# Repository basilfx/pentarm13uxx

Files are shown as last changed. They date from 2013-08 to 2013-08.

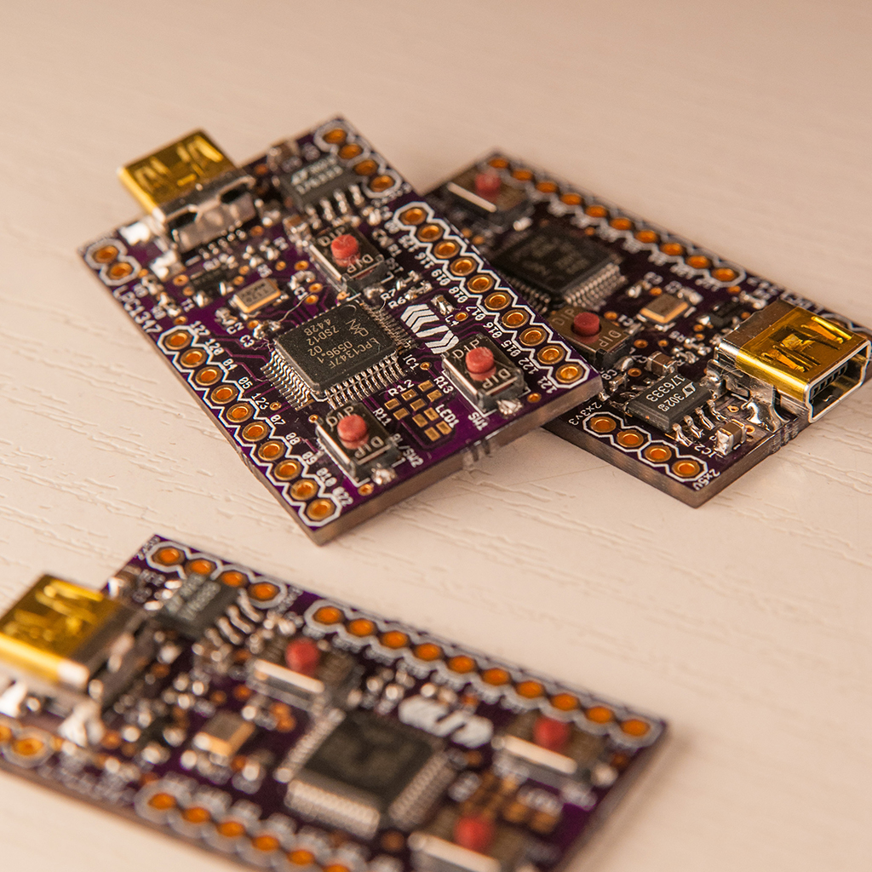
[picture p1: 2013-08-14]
doc/pcb.jpg

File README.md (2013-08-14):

endorse (http://coderwall.com/sebseb7)

pentarm13uxx
============

A small template project (blinking led) for the new lpc1347 (successor of the popular lpc1343).

Including Makefile, linker-script and cmsis and microcontroler header files.

Also includes eagle files for a small breaboardable eval-board.

- - -

####lpc1347 features

* 12k sram (was 8k)
* 64k flash (was 32k)
* 4k EEPROM (new)
* 72Mhz
* USART,I2C,2xSPI
* 12Bit ADC (new)
* USB_MSC, USB_HID, USB_CDC and USB_DFU in rom (new)
* usb-bootloader in rom

- - -

price of the eval board: ~$15

- - -

####BOM:

* C1,C2 : 22pF 0402
* C3,C4 : 100nF 0402
* C6,C8 : 10nF 0402
* C5,C7 : 1µF 0805
* R2,R3,R6,R7 : 150R 0402
* R4,R5 : 33R 0402
* R1,R8,R9 : 15k 0402
* R10 : 1k5 0402
* T1 : Si3102DS SOT23 (or other pfet)
* Q1 : 12Mhz MT (farnell: 1842056)
* IC1 : lpc1347 QFP48 (farnell: 2103477)
* IC2 : LT1763CS8-3.3 SOIC8 (farnell: 1273617)
* X1 : Mini USB Connector SMD (farnell: 1125348)
* X2,X3 : Pin-Header 10 Pin
* X4 : Pin Header 2 Pin
* X5 : Pin Header 4 Pin
* LED1 : RGB LED PLCC4 common annode
* SW1,SW2,RST : MCTAEF-25N (farnell:1605484)

- - -

data sheet  : http://www.nxp.com/documents/data_sheet/LPC1315_16_17_45_46_47.pdf

user manual : http://www.nxp.com/documents/user_manual/UM10524.pdf

toolchain   : https://launchpad.net/gcc-arm-embedded

- - -   
brd
Board top render

pcb Completed boards, photo by [Dirk Soeteman](http://www.dirksoeteman.nl/)

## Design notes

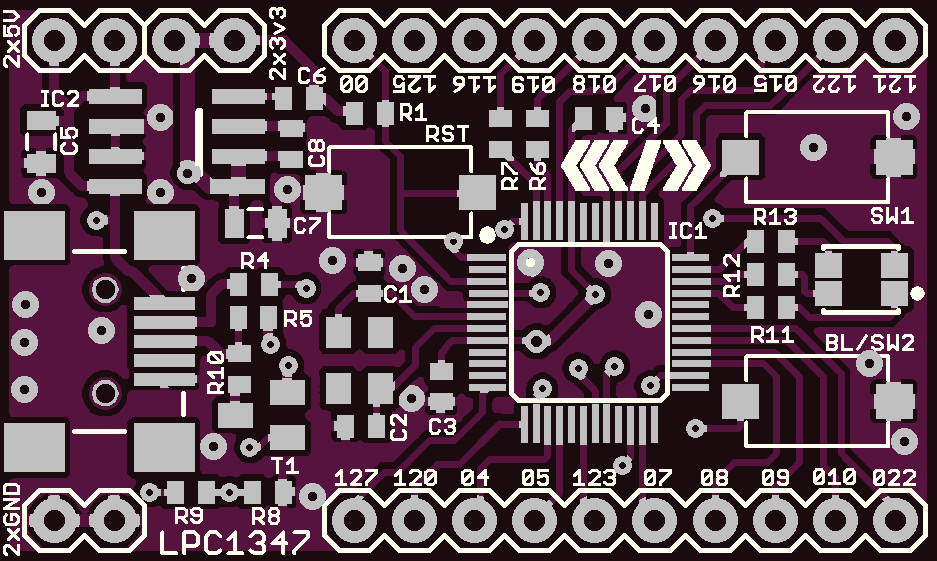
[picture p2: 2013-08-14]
doc/brd.png

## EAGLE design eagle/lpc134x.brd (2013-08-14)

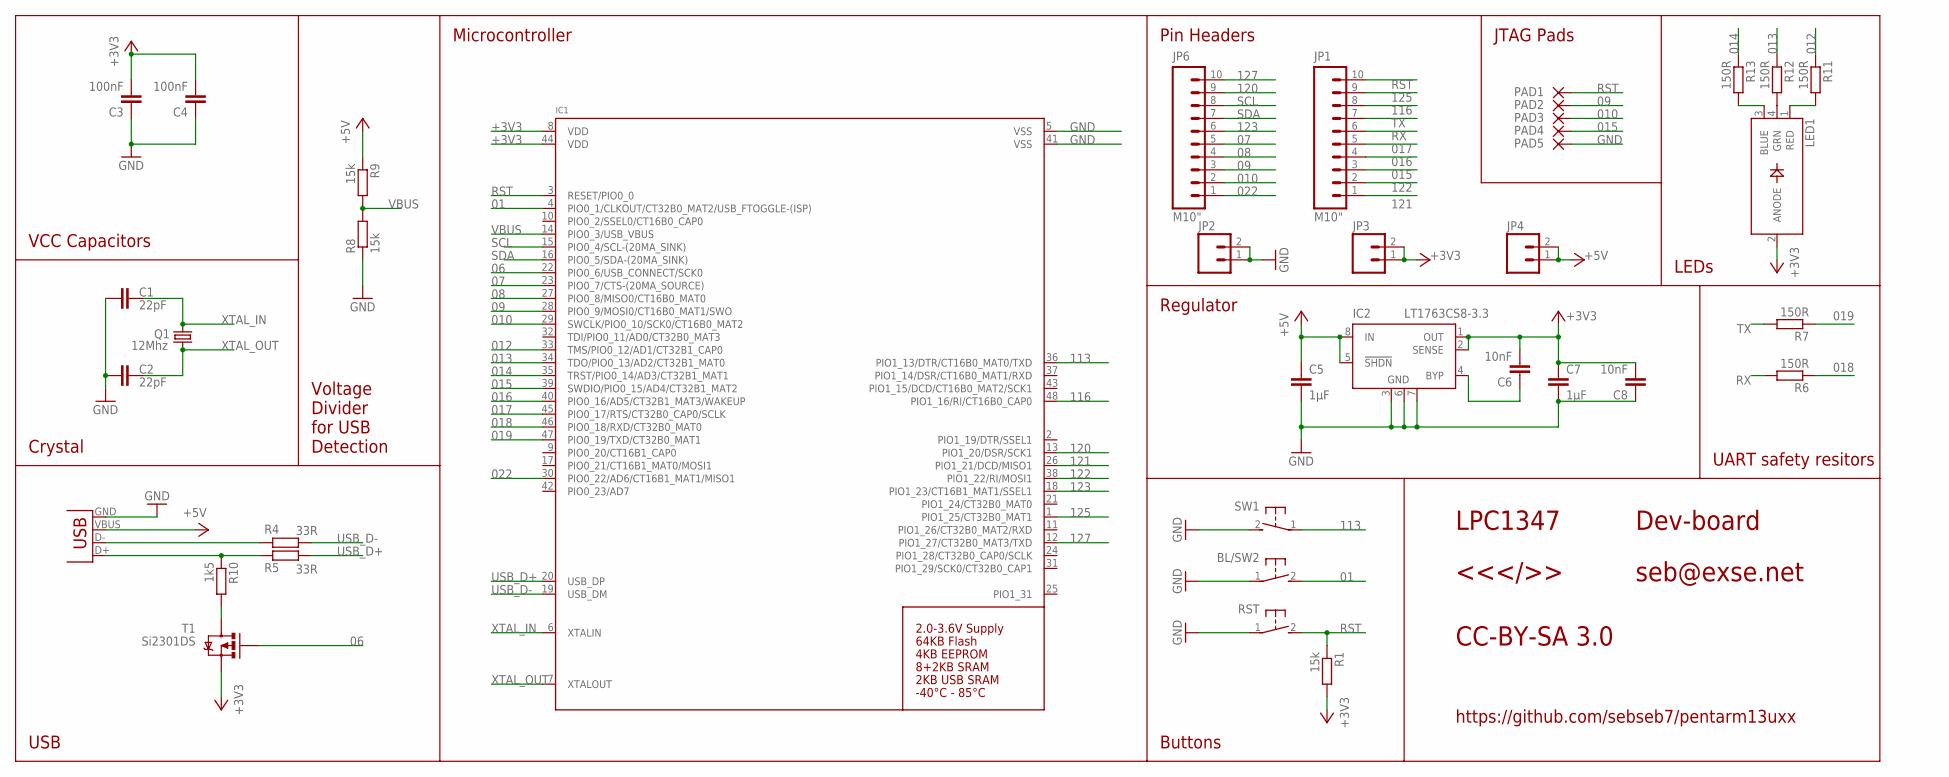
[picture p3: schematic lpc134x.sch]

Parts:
BL/SW2: SWITCH_MCTAEF
C1, C2: 22pF; C0402
C3, C4: 100nF; C0402
C5, C7: 1µF; 0805
C6, C8: 10nF; C0402
IC1: LPC1347_QFP48; LQFP48
IC2: LT1763CS8-3.3; SOIC8
JP1, JP6: M10"; 1X10
JP2, JP3, JP4: M02PTH; 1X02
LED1: LED_RGB_PLCC4; RGBLED_PLCC4
PAD1, PAD2, PAD3, PAD4, PAD5: WIREPADSMD1,27-254; SMD1,27-2,54
Q1: 12Mhz; MT
R1, R8, R9: 15k; R0402
R4, R5: 33R; R0402
R6, R7, R11, R12, R13: 150R; R0402
R10: 1k5; R0402
RST: SWITCH_MCTAEF
SW1: SWITCH_MCTAEF
T1: Si2301DS; SOT23
X2: USB-SMD-NS; USB-MINIB-NOSTOP

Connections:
01: BL/SW2.2, IC1.4 (PIO0_1/CLKOUT/CT32B0_MAT2/USB_FTOGGLE-(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)
06: IC1.22 (PIO0_6/USB_CONNECT/SCK0), T1.1 (G)
07: IC1.23 (PIO0_7/CTS-(20MA_SOURCE)), JP6.5
08: IC1.27 (PIO0_8/MISO0/CT16B0_MAT0), JP6.4
09: IC1.28 (PIO0_9/MOSI0/CT16B0_MAT1/SWO), JP6.3, PAD2.1
010: IC1.29 (SWCLK/PIO0_10/SCK0/CT16B0_MAT2), JP6.2, PAD3.1
012: IC1.33 (TMS/PIO0_12/AD1/CT32B1_CAP0), R11.1
013: IC1.34 (TDO/PIO0_13/AD2/CT32B1_MAT0), R12.1
014: IC1.35 (TRST/PIO0_14/AD3/CT32B1_MAT1), R13.1
015: IC1.39 (SWDIO/PIO0_15/AD4/CT32B1_MAT2), JP1.3, PAD4.1
016: IC1.40 (PIO0_16/AD5/CT32B1_MAT3/WAKEUP), JP1.4
017: IC1.45 (PIO0_17/RTS/CT32B0_CAP0/SCLK), JP1.5
018: IC1.46 (PIO0_18/RXD/CT32B0_MAT0), R6.1
019: IC1.47 (PIO0_19/TXD/CT32B0_MAT1), R7.1
022: IC1.30 (PIO0_22/AD6/CT16B1_MAT1/MISO1), JP6.1
113: IC1.36 (PIO1_13/DTR/CT16B0_MAT0/TXD), SW1.1
116: IC1.48 (PIO1_16/RI/CT16B0_CAP0), JP1.8
120: IC1.13 (PIO1_20/DSR/SCK1), JP6.9
121: IC1.26 (PIO1_21/DCD/MISO1), JP1.1
122: IC1.38 (PIO1_22/RI/MOSI1), JP1.2
123: IC1.18 (PIO1_23/CT16B1_MAT1/SSEL1), JP6.6
125: IC1.1 (PIO1_25/CT32B0_MAT1), JP1.9
127: IC1.12 (PIO1_27/CT32B0_MAT3/TXD), JP6.10
+3V3: C3.2, C4.2, C6.2, C7.1, C8.2, IC1.8 (VDD), IC1.44 (VDD), IC2.1 (OUT), IC2.2 (SENSE), JP3.1, JP3.2, LED1.2 (ANODE), R1.2, T1.2 (S)
+5V: C5.1, IC2.5 (!SHDN), IC2.8 (IN), JP4.1, JP4.2, R9.1, X2.VBUS
GND: BL/SW2.1, C1.1, C2.1, C3.1, C4.1, C5.2, C7.2, C8.1, IC1.5 (VSS), IC1.41 (VSS), IC2.3 (GND), IC2.6 (GND), IC2.7 (GND), JP2.1, JP2.2, PAD5.1, R8.1, RST.1, SW1.2, X2.GND
unnamed: LED1.1 (RED), R11.2
unnamed: LED1.4 (GRN), R12.2
unnamed: LED1.3 (BLUE), R13.2
unnamed: R5.2, R10.1, X2.D+
unnamed: R4.2, X2.D-
unnamed: C6.1, IC2.4 (BYP)
unnamed: R10.2, T1.3 (D)
RST: IC1.3 (RESET/PIO0_0), JP1.10, PAD1.1, R1.1, RST.2
RX: JP1.6, R6.2
SCL: IC1.15 (PIO0_4/SCL-(20MA_SINK)), JP6.8
SDA: IC1.16 (PIO0_5/SDA-(20MA_SINK)), JP6.7
TX: JP1.7, R7.2
USB_D+: IC1.20 (USB_DP), R5.1
USB_D-: IC1.19 (USB_DM), R4.1
VBUS: IC1.14 (PIO0_3/USB_VBUS), R8.2, R9.2
XTAL_IN: C1.2, IC1.6 (XTALIN), Q1.3 (2)
XTAL_OUT: C2.2, IC1.7 (XTALOUT), Q1.1

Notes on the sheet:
Pin Headers
Regulator
Buttons
LEDs
UART safety resitors
Microcontroller
Voltage Divider for USB Detection
Crystal
VCC Capacitors
USB
CC-BY-SA 3.0
seb@exse.net
<<</>>
LPC1347
Dev-board
https://github.com/sebseb7/pentarm13uxx
JTAG Pads

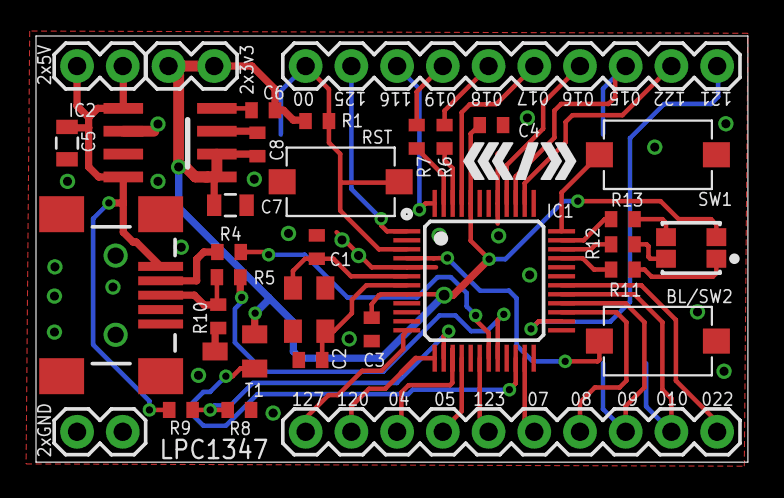
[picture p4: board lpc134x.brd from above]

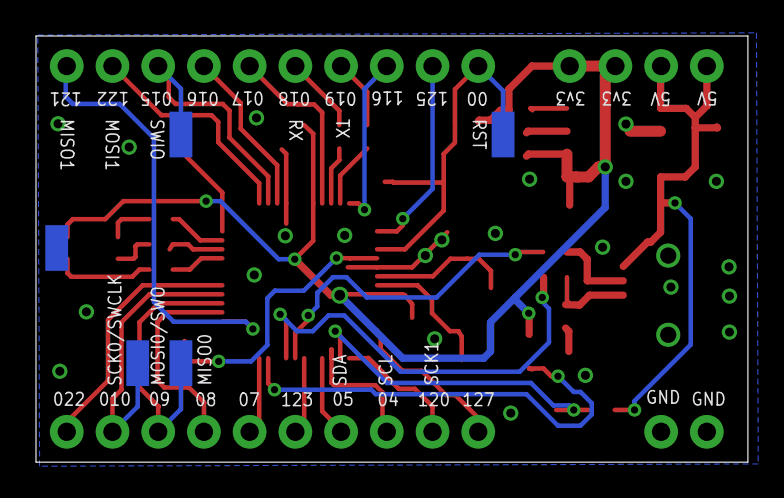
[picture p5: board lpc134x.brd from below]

Board: 2 copper layers, 39.5 x 23.7 mm, 39 parts (5 on the bottom side), 43 nets.

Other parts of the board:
U$2: C3D2_LOGO_SMALL

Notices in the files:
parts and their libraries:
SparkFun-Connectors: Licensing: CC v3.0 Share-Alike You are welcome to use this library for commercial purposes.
